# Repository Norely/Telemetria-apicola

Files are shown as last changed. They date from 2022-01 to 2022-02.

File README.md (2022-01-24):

# Telemetria-apicola
Screenshot from 2021-11-02 09-18-42

# Integrantes:
 - Juan Sebastian Martinez Valbuena
 - Elkin Alejandro Romero Hernandez
 - Gustavo Olarte Romero
 - Norely Jimenez Melenge

# ¿En que consiste el producto?
El producto consiste es un sistema de embebido que permite sensar la temperatura y mantenerla desde los 12°C hasta los 35°C,ya que en un apiario es importante que la temperatura no exceda los 38°C,para evitar que las abejas realizan trabajo extra,como salir a traer agua o realizar ventilación con sus alas. Además cuenta con un sistema de GPs que envía una notificación al celular,  en el cual es necesario para obtener la certificación que identifique su posición geográfica.

El módulo medirá temperatura, humedad y llenado de los tanques. Los actuadores constaría de un ventilador para refrigerar el ambiente y una resistencia en caso de requerir aumento de temperatura. Cuando los tanques estén llenos el módulo envía un mensaje de alerta a la interfaz que se haya elegido. También se puede incluir un módulo de alimentación artificial para que suministre agua azucarada en caso de ser necesario (se realizará 45 días antes de la floración y se suspende al inicio de la misma). 

# Componentes basicos
- ESP32 (Microcontrolador)
- Raspberry (Servidores)
- Sensor de humedad DHT11 (DIGITAL)  (12 - 35)°C
- Pantalla OLED
- Ventilador
- Microbomba
- Neo m7 (GPS)
- Regulador ASM1117 3.3V
- Driver L293D
- Convertidor MT3608
- BQ24070

# Requerimientos funcionales
* El apiario debe recopilar constantemente las variables de interés (temperatura y humedad)
* El sistema recolecta datos automáticamente para enviarlos a un servidor local.
* Mantener un ambiente controlado (parámetros ambientales)
* El sistema tendrá una Interfaz hombre máquina que permita la visualización de los parámetros medidos
* El apiario debe poseer módulos removibles para la obtención de miel.
* El sistema cuenta con monitoreo y control por parte del usuario en caso de falla de cualquier dispositivo electrónico.

# Requerimientos no funcionales
* El apiario debe funcionar todo el día.
* Debe garantizar la calidad apropiada de la miel
* El apiario debe usarse sólo por personal calificado.
* La interfaz hombre-máquina debe ser responsive.

# Hardware
***ESP 32***

Para pruebas del firmware y algunos componentes se hará uso de la siguiente tarjeta:
  
  
|Pin| Protocolo | Nombre |Dispositivo|
|-----|---|---|-----|
|33|I2C|SDA|Pantalla|
|36|I2C|SCL|Pantalla|
|34|UART|Rx|USB|
|35|UART|Tx|USB|
|23|UART|Rx|GPS|
|27|UART|Tx|GPS|
|24|GPIO| |Sensor T/H|
|26| | |Ventilador|
|29| | |Microbomba|
|13| | |Rele Bombilla|

Este tiene las siguientes caracteristicas:
- Procesador Tensilica Xtensa 32bits LX6 hasta 240MHz.
- Wi-Fi: 802.11b/g/n/e/i (802.11n @ 2.4 Ghz hasta 150 Mbit/s).
- Bluetooth: v4.2 BR/EDR y bluetooth  Low Energy (BLE).
- Rom:448 KiB.
- SRAM: 520 KiB.
- RTC slow SRAM: 8 KiB.
- RTC fast SRAM: 8 KiB.
- eFuse: 1 Kbit.
- Flash embebida: 0 MiB (ESP32-D0WDQ6, ESP32-D0WD, and ESP32-S0WD chips); 2 MiB (ESP32-D2WD chip); 4 MiB (ESP32-PICO-D4 SIP module).
- Periféricos compatibles: ADC, DAC, I2C, UART, Interfaz CAN 2.0, SPI, I2S, RMII y PWM entre otros.
- Seguridad tipo IEEE 802.11, WFA, WPA/WPA2 y WAPI.
- Encriptación de memoria Flash.
- Criptografía soportada por acelerador de hardware: AES, SHA-2, RSA, ECC, RNG.
- Voltaje de trabajo 3.3VDC.
- Energía y datos  via conector microUSB 5VDC.

En la tarjeta que estamos desarrollando se emplea el siguiente módulo (Esp 32-WROOM-32D): 
<p align="center">
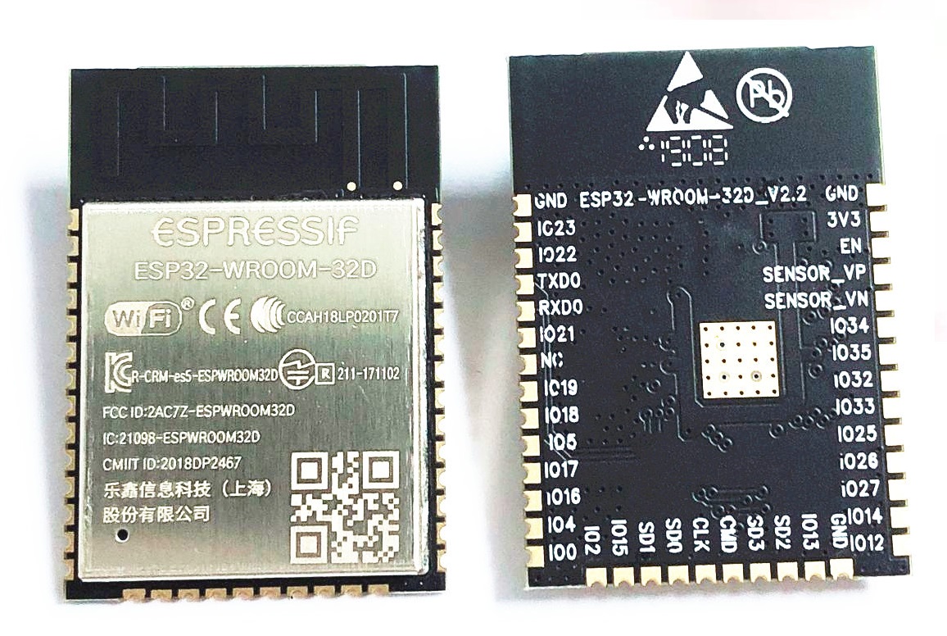
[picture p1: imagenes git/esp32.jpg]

</p>

Este se encuentra en SIGMA ELECTRONICA ([ESP 32](https://www.sigmaelectronica.net/producto/esp32-wroom-32d/)) y tambien su [Hoja de datos](https://github.com/Norely/Telemetria-apicola/blob/main/Hojas%20de%20datos/ESP32-WROOM-32D_pdf.pdf) de donde se puede obtener el esquematico de los perifericos para el módulo:

<p align="center">
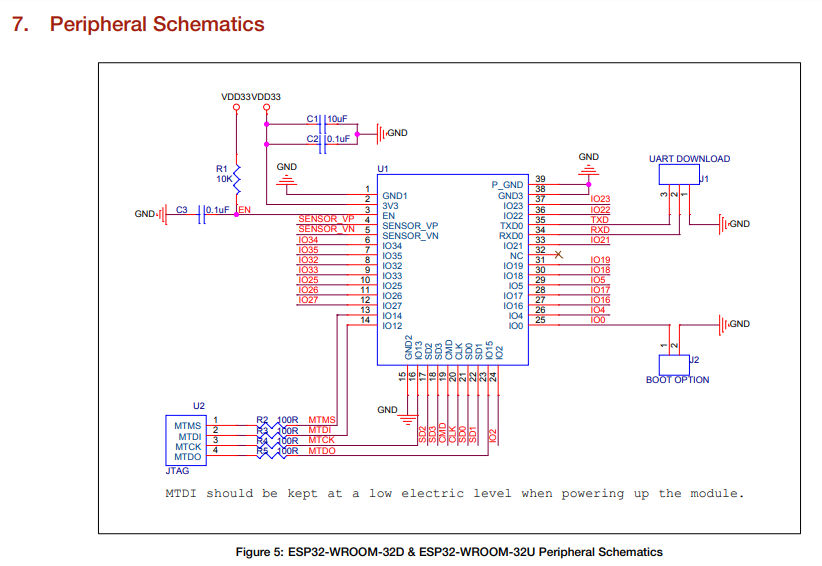
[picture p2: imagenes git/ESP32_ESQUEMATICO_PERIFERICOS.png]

</p>

***Raspberry PI4-4GB***

Esta tarjeta se considera para el montaje del servidor en donde se planea guardar la información obtenida del proyecto. 

<p align="center">
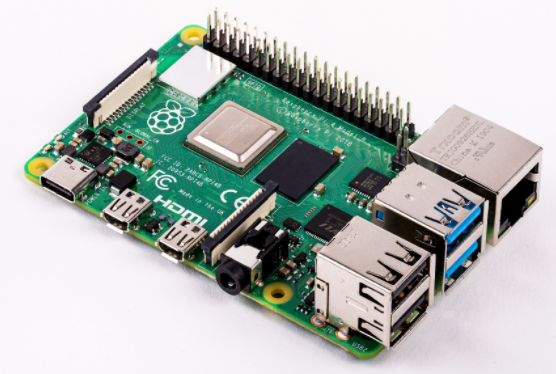
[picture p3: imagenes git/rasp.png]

</p>

Especificaciones:
- BCM2711 Broadcom, Quad Core Cortex-A72.
- 64-bit SoC @ 1,5 GHz.
- Memoria RAM: 4 GB.
- 2.4 GHz y 5.0 GHz IEEE 802.11b/g/n/ac inalámbrico LAN.
- Bluetooth 5.0 BLE.
- Gigabit Ethernet.
- 2 Puertos USB 2.0.
- 2 Puertos USB 3.0.
- Conector GPIO estándar de 40 pines (Totalmente compatible con las placas de desarrollo Raspberry PI anteriores).
- 2 puertos micro HDMI (compatible con hasta 4Kp60).
- Puerto de visualización MIPI DSI de 2 vías.
- Puerto de camara MIPI de 2 carriles.
- Puerto de vídeo compuesto y audio estéreo de 4 polos.
- H.265 (decodificador de 4Kp60).
- H.264 (decodificador 1080p60, 1080p30).
- OpenGL ES 3.0 gráficos.
- Ranura para tarjeta Micro SD para cargar el sistema operativo y el almacenamiento de datos.
- Alimentación de entrada por conector USB Tipo C: 5V – 3A.
- Alimentación de entrada por conector GPIO: 5V – 3A.
- Alimentación sobre Ethernet (PoE) habilitada (requiere un complemento adicional PoE por separado): 5V – 3A.

Este se encuentra en SIGMA ELECTRONICA ([RPI4-4GB](https://www.sigmaelectronica.net/producto/rpi4-4gb/)) y tambien su [Hoja de datos](https://github.com/Norely/Telemetria-apicola/blob/main/Hojas%20de%20datos/RASP.pdf)

***Sensor de humedad DHT11***

Este sensor permite obtener la lectura de temperatura y humedad, ademas su señal es digital por lo que facilita su comunicacion con la ESP 32.

<p align="center">
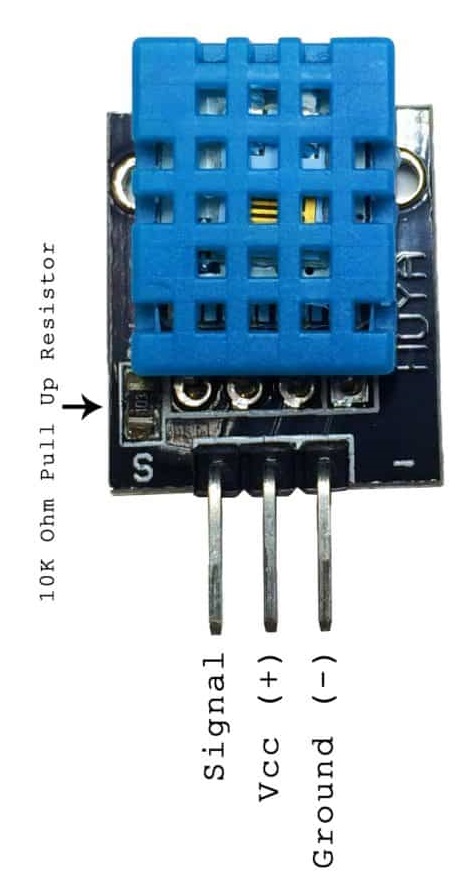
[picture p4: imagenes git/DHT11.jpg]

</p>

Especificaciones:
- humedad relativa 
-Resolución: 16 bit 
- Repetibilidad: ± 1% HR 
- Precisión: En 25 ℃ ± 5% de humedad relativa 
- Intercambiabilidad: totalmente intercambiables 
- Tiempo de respuesta: 1 / e (63%) de 25 ℃ 6s 1m / s 6s aire 
- Histéresis: <± 0,3% HR 
- Estabilidad a largo plazo: <± 0.5% RH / yr in temperatura 
- Resolución: 16 bit 
- Repetibilidad: ± 0,2 ℃ 
- Rango: A los 25 ℃ ± 2 ℃ 
- Tiempo de respuesta: 1 / e (63%) 10S 
- Características eléctricas 
- Fuente de alimentación: CC 3.5 ~ 5.5V 
- Corriente de alimentación: medida 0.3mA espera 60μ A 
- Periodo de muestreo: más de 2 segundos

Este se encuentra en SIGMA ELECTRONICA ([DHT11](https://www.sigmaelectronica.net/producto/dht11/)) y tambien su [Hoja de datos](https://github.com/Norely/Telemetria-apicola/blob/main/Hojas%20de%20datos/DHT11.pdf).

***Pantalla OLED***

Se elige una pantalla OLED como recomendación del docente porque es mas eficiente energeticamente y ademas a la cantidad de pixeles que manejan.

<p align="center">
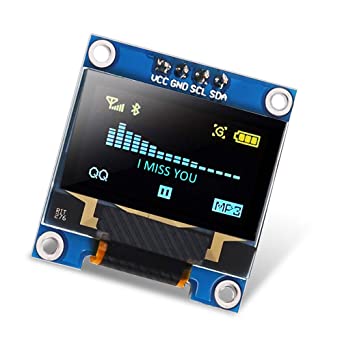
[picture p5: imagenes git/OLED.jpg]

</p>

Especificaciones:
- No necesita backlight.
- Color:Azul
- Resolución: 128x64.
- Voltaje: 3 a 5V.
- Temperatura de trabajo: -30ºC a 70ºC.
- Tamaño: 27 x 27 x 4.1 mm
- Interfaz: I2C IIC TWI
- Driver: SSD1306
- Consumo: 0.08W

Este se encuentra en Dualtronica ([Pantalla OLED](https://dualtronica.com/pantallas/396-pantalla-oled-096-azul-comunicacion-i2c.html)). La [Hoja de datos](https://github.com/Norely/Telemetria-apicola/blob/main/Hojas%20de%20datos/SSD1306.pdf) corresponde al driver SSD1306 .

***Ventilador***

El medio de refrigeracion que se empleará será un ventilador PI.

<p align="center">
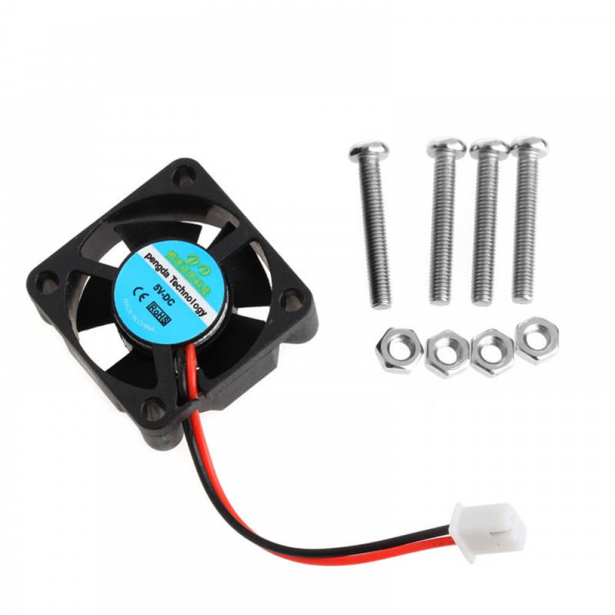
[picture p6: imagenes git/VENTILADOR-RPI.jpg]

</p>

Especificaciones: 
- Voltaje de funcionamiento: 5 V.
- Corriente nominal: 0.2 A.
- Dimensiones: 30 mm x 30 mm x 10 mm.

Este se encuentra en SIGMA ELECTRONICA ([Ventilador RPI](https://www.sigmaelectronica.net/producto/ventilador-pi/)) y su [Hoja de datos](https://github.com/Norely/Telemetria-apicola/blob/main/Hojas%20de%20datos/VENTILADOR.pdf).

***Microbomba***

Para surtir alimentación artificial al apiario, se emplea el uso de esta microbomba. Se eligío por encima de la valvula solenoide porque esta requiere un caudal minimo ademas de su relativo costo elevado. 

<p align="center">
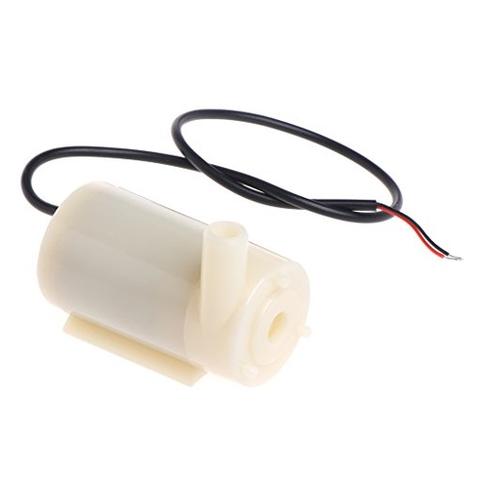
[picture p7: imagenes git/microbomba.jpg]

</p>

Especificaciones:
- Voltaje de Alimentación: 2.5-6VDC.
- Elevación máxima: 40-110cm.
- Caudal: 80-100L/H.
- Diámetro exterior de la salida de agua: 7.5 mm.
- Diámetro interior de salida de agua: 4.7 mm.
- Diámetro : Aprox. 24 mm.
- Longitud: Aprox. 45 mm.
- Altura: aprox. 33 mm.
- Material: Plástico.
- Vida útil de trabajo continuo de 500 horas.

Este se encuentra en SIGMA ELECTRONICA ([Microbomba](https://www.sigmaelectronica.net/producto/sig0833/)).

***Neo M6***

Se emplea el módulo NEO-6M para emplearlo a parte de la tarjeta a desarrollar dadas las condiciones que requiere un modulo gps en la misma tarjeta como estar lejos de ciertos componentes como capacitores, ademas de la antena de la esp 32 con la que podria haber interferencia.

<p align="center">
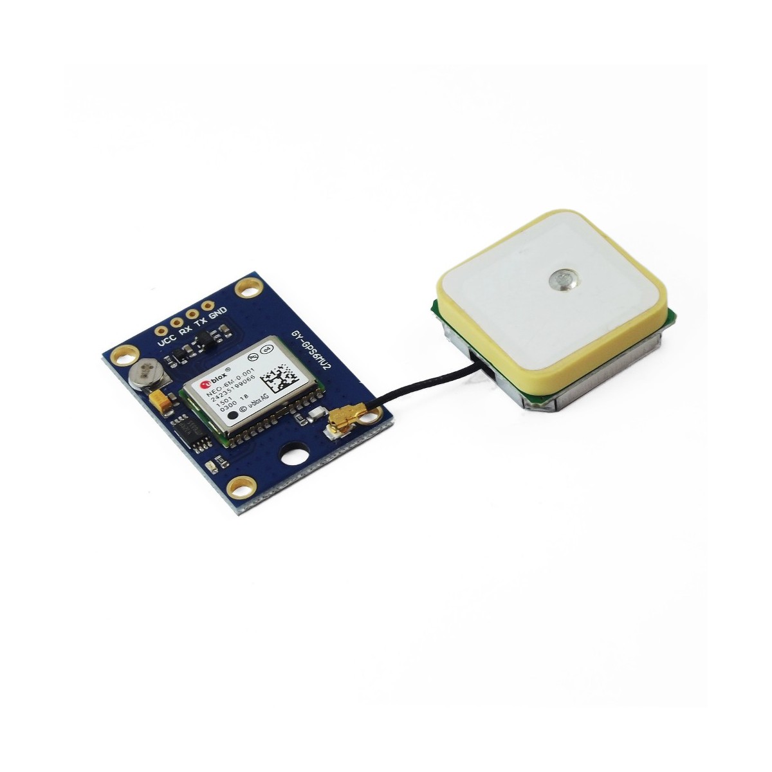
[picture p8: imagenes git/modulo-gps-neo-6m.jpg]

</p>

Especificaciones:
- Ultra sensibilidad: -165dBm
- 22 tracking/66 acquisition-channel receiver
- Coporta estándares WAAS/EGNOS/MSAS/GAGAN
- Frecuencia de actualización 5Hz velocidad de desplazamiento máxima: 500m/seg
- Protocolo NMEA  (a 9600bps)
- 01 puerto serial
- Antena incorporada de 18.2 x 18.2 x 4.0 mm
- Rango de temperatura: -40 to 85 C
- Cumple estándar RoHS
- Tamano reducido 30mm x20mm x 11.4mm

Este se encuentra en Dualtronica ([GPS NEO-6M](https://dualtronica.com/modulos/86-modulo-gps-neo-6m.html)) y su [Hoja de datos](https://github.com/Norely/Telemetria-apicola/blob/main/Hojas%20de%20datos/GY-NEO-6M-V2-pdf.pdf).

# Software
  

Para esta parte se realiza la [instalación](https://docs.micropython.org/en/latest/esp32/tutorial/intro.html#esp32-intro) para el ESP-32, del firmware mycropython. 
  
Este compilador permite realizar algunas acciones como la manipulación de los pines del microcontrolador, Interactuar con los protocolos de comunicacion (I2C, SPI, PWM, etc), Manejo de tiempos entre muchas otras.

## Ejemplos:

#### Pins
~~~
from machine import Pin

p0 = Pin(0, Pin.OUT)    # create output pin on GPIO0
p0.on()                 # set pin to "on" (high) level
p0.off()                # set pin to "off" (low) level
p0.value(1)             # set pin to on/high

p2 = Pin(2, Pin.IN)     # create input pin on GPIO2
print(p2.value())       # get value, 0 or 1

p4 = Pin(4, Pin.IN, Pin.PULL_UP) # enable internal pull-up resistor
p5 = Pin(5, Pin.OUT, value=1) # set pin high on creation
~~~

#### Protocolo
~~~
from machine import Pin, SoftI2C

i2c = SoftI2C(scl=Pin(5), sda=Pin(4), freq=100000)

i2c.scan()              # scan for devices

i2c.readfrom(0x3a, 4)   # read 4 bytes from device with address 0x3a
i2c.writeto(0x3a, '12') # write '12' to device with address 0x3a

buf = bytearray(10)     # create a buffer with 10 bytes
i2c.writeto(0x3a, buf)  # write the given buffer to the peripheral
~~~

#### Tiempo
~~~
import time

time.sleep(1)           # sleep for 1 second
time.sleep_ms(500)      # sleep for 500 milliseconds
time.sleep_us(10)       # sleep for 10 microseconds
start = time.ticks_ms() # get millisecond counter
delta = time.ticks_diff(time.ticks_ms(), start) # compute time difference
~~~

# Modelo 3D Diseño PCB

<p align="center">
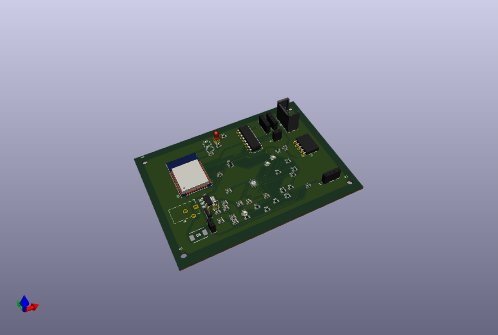
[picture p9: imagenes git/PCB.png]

</p>

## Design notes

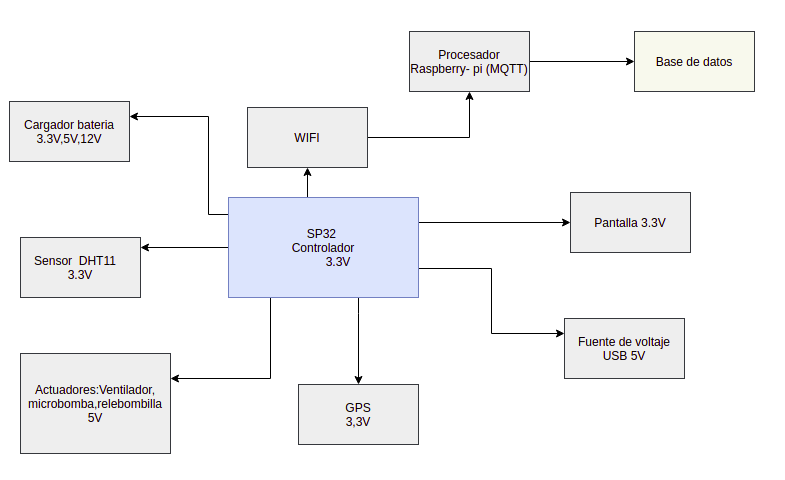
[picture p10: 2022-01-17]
DiagramaBloques.png

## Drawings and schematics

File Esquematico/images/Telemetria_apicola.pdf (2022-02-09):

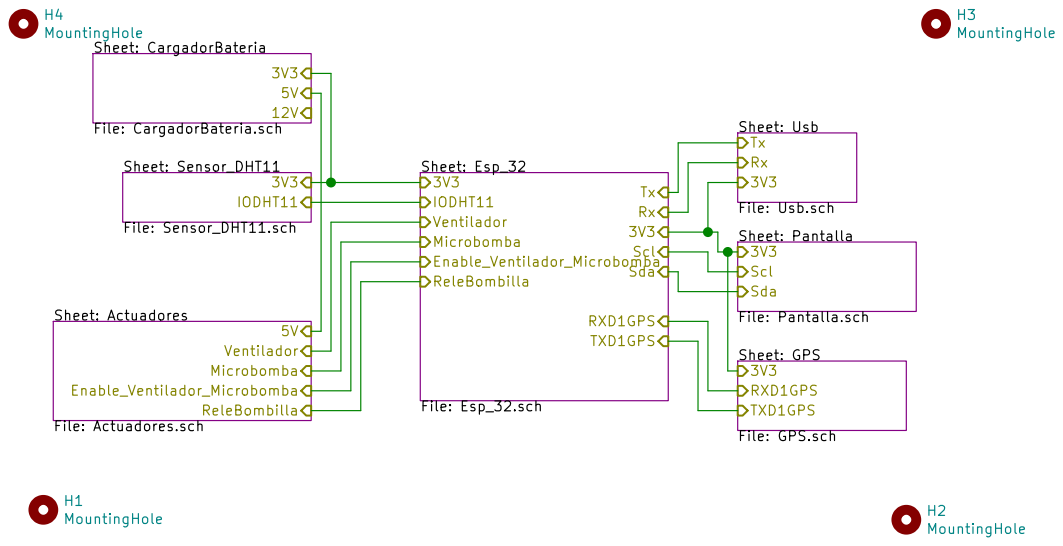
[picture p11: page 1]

TXD1GPS ReleBombilla Sheet: Sensor_DHT11 File: Sensor_DHT11.sch

Sheet: Pantalla File: Pantalla.sch

3V3 Sheet: Actuadores File: Actuadores.sch

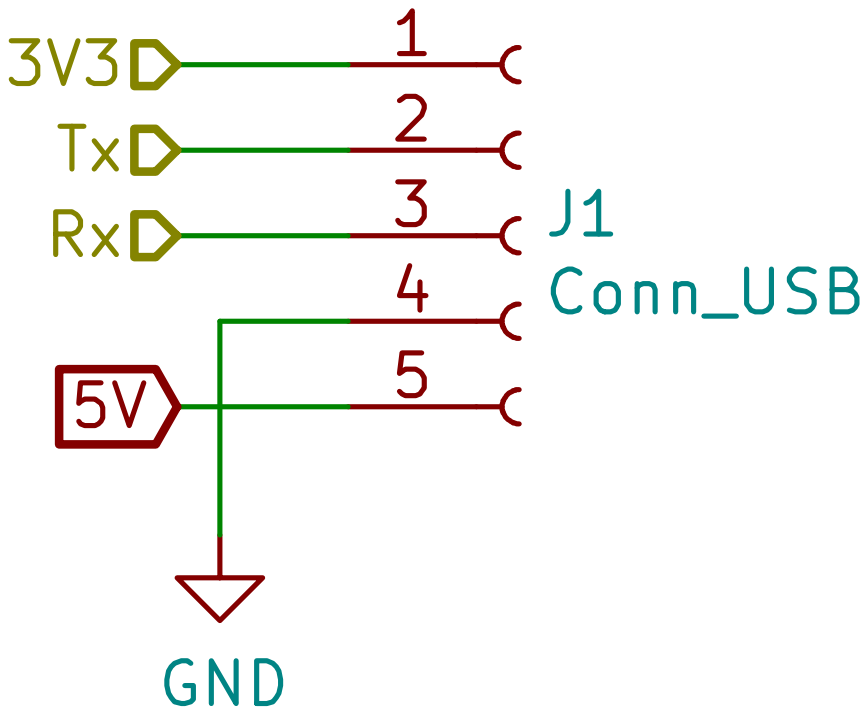
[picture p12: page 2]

Id: 2/8 Title: File: Usb.sch Sheet: /Usb/ GND

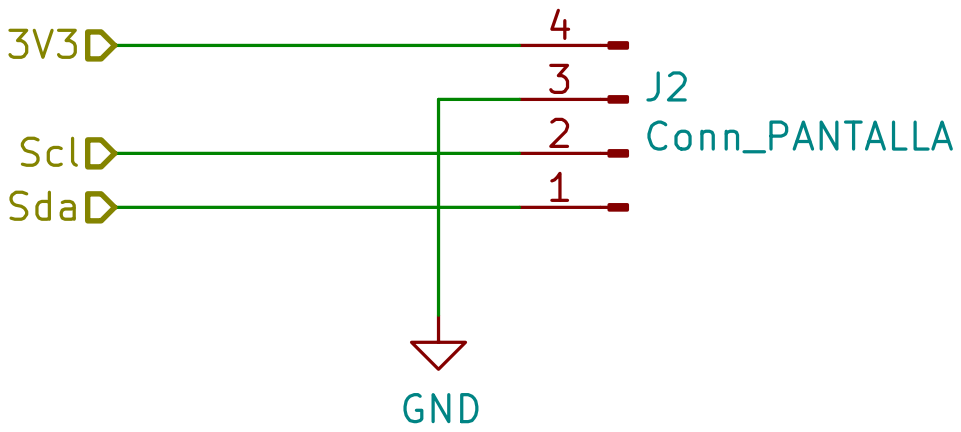
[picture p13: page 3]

Id: 3/8 Title: File: Pantalla.sch Sheet: /Pantalla/

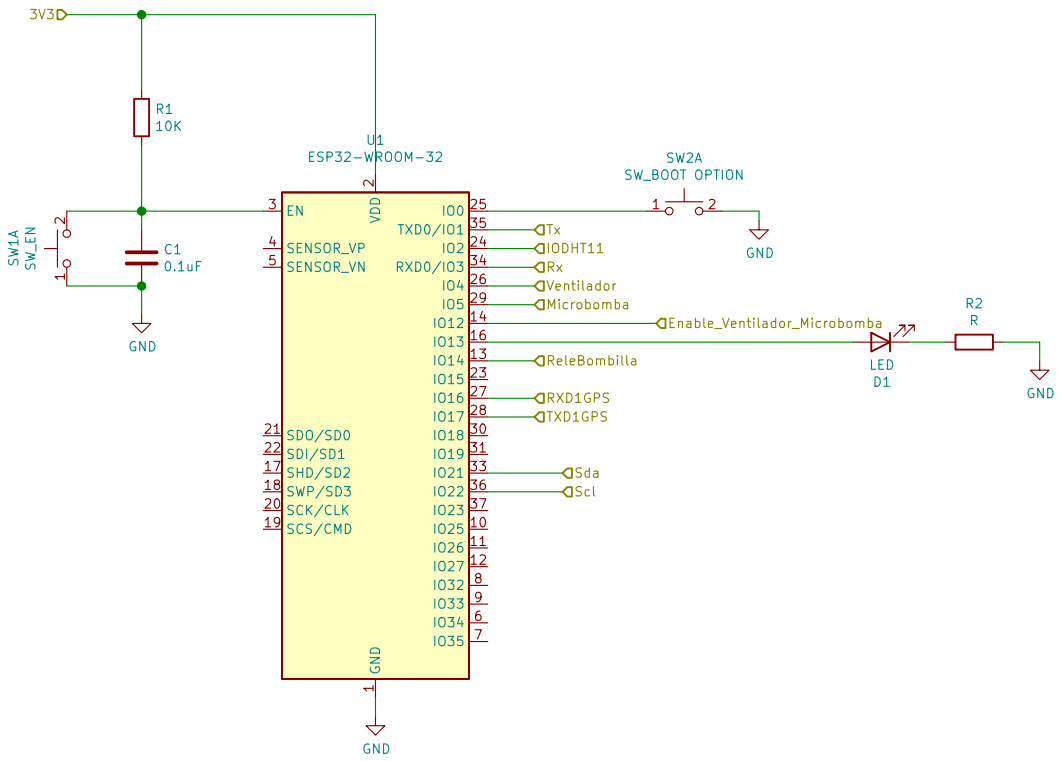
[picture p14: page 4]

2 SCK/CLK 20 SDO/SD0 21 SDI/SD1 22

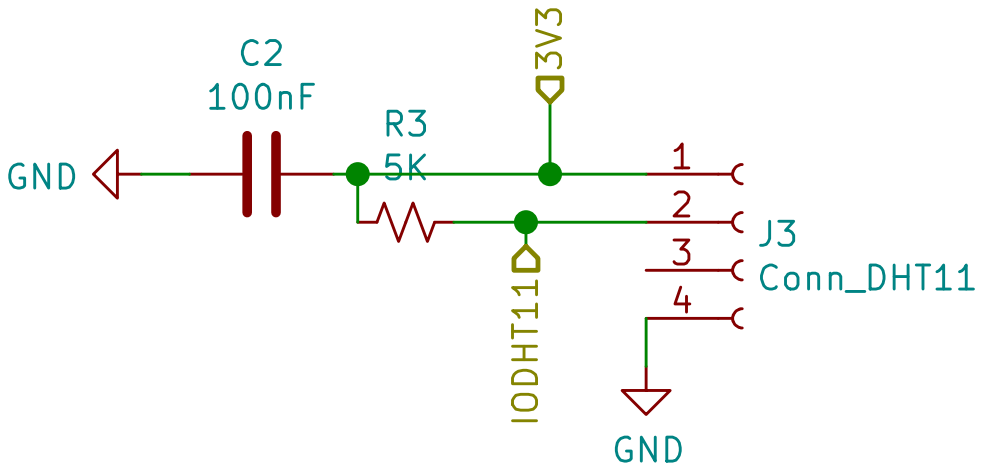
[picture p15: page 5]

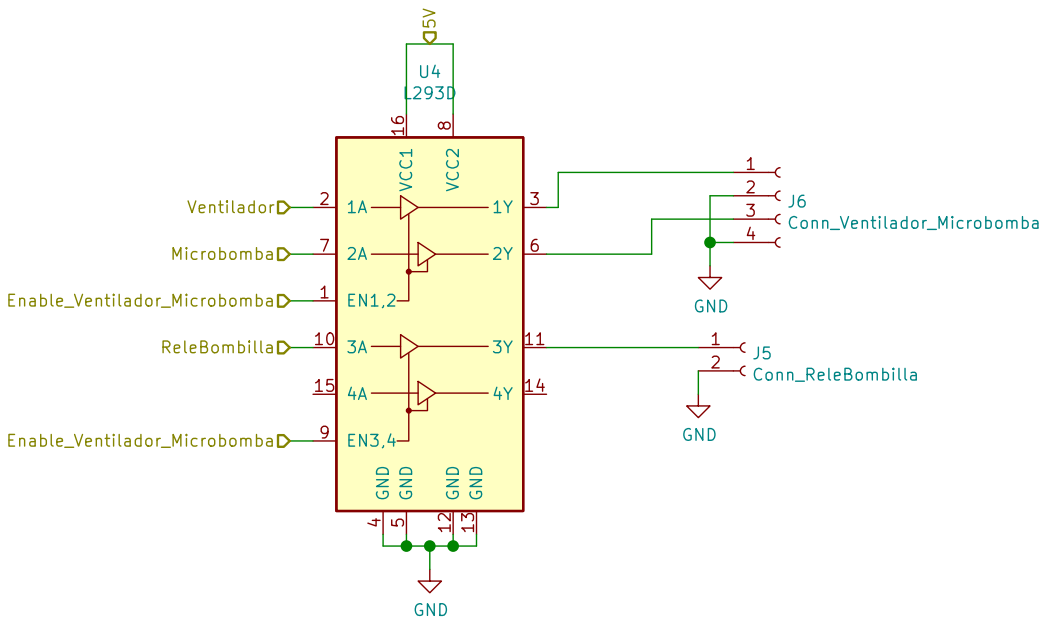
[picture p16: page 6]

Id: 6/8 Title: File: Actuadores.sch Sheet: /Actuadores/

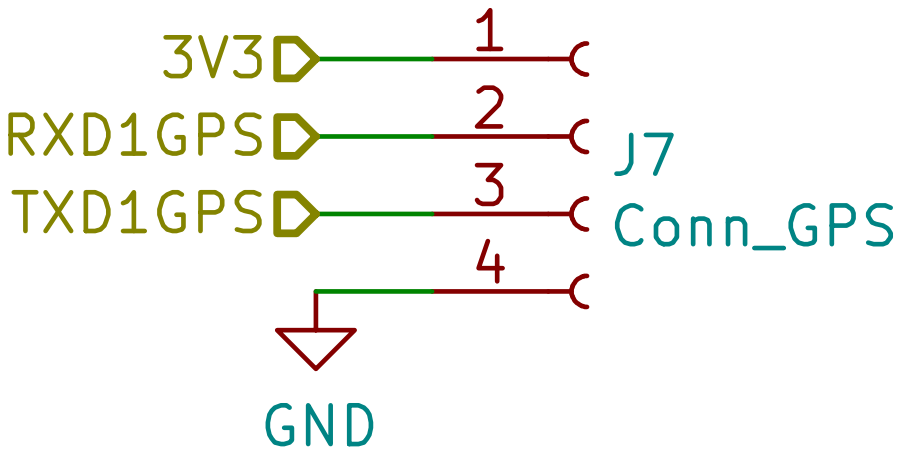
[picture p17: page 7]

Id: 7/8 Title: File: GPS.sch Sheet: /GPS/

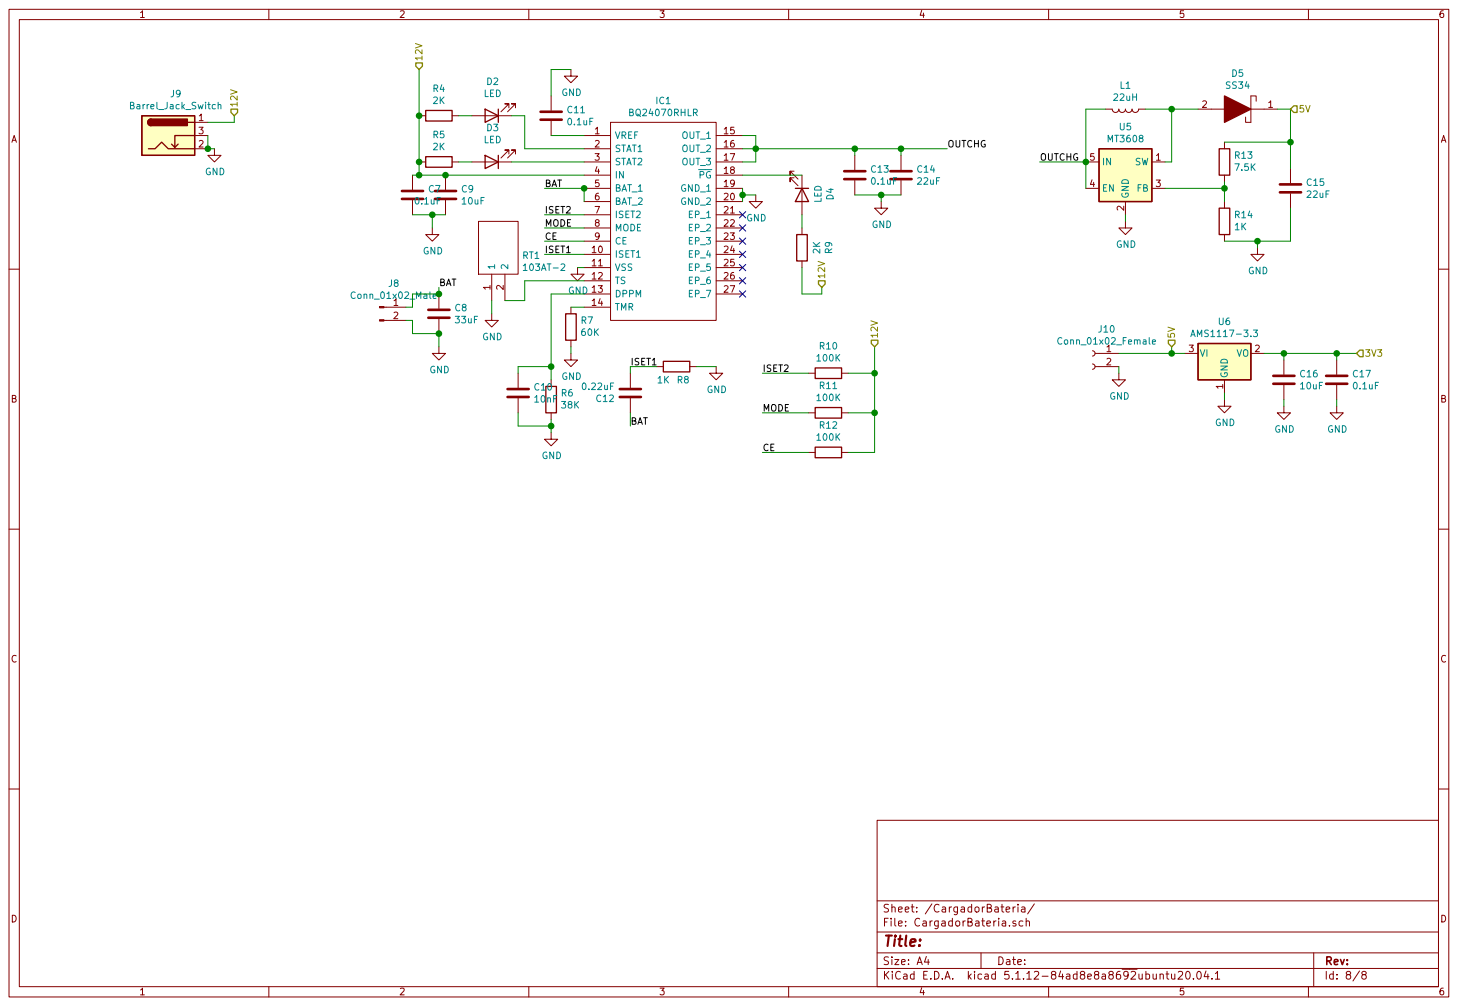
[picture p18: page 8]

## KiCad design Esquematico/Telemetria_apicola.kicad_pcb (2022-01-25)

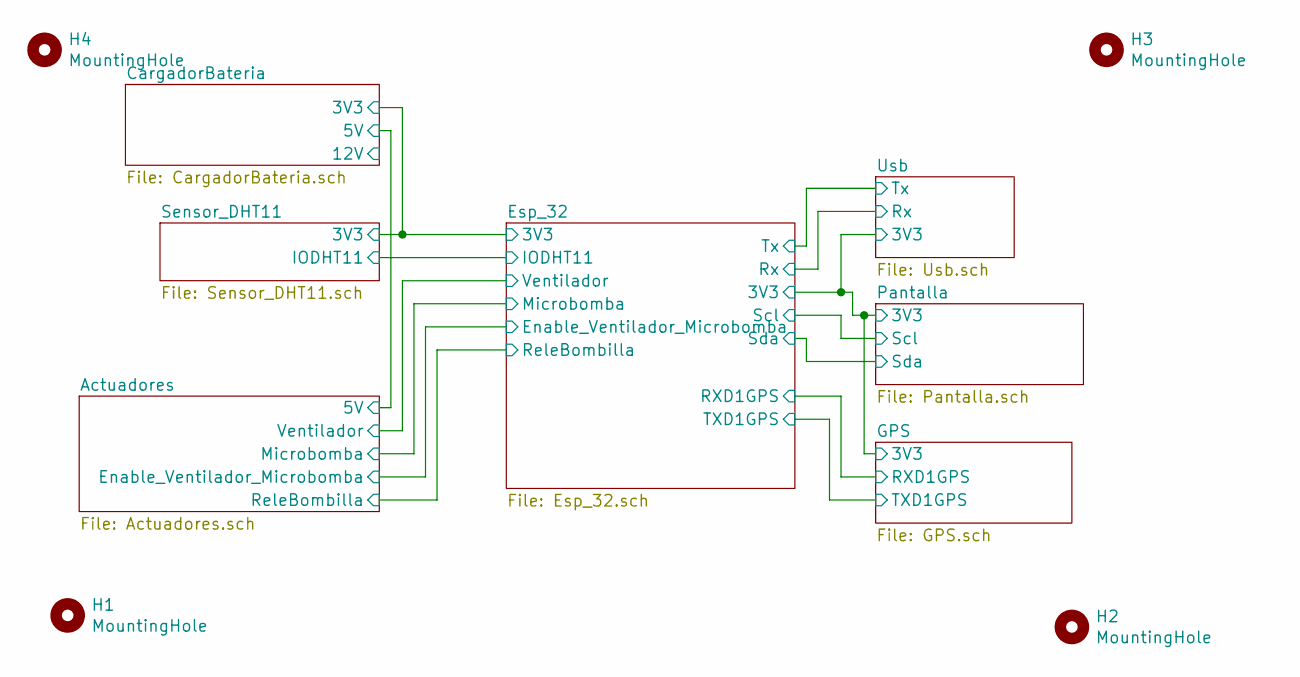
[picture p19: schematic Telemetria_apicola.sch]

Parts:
H1, H2, H3, H4: MountingHole; MountingHole_3.2mm_M3_ISO7380

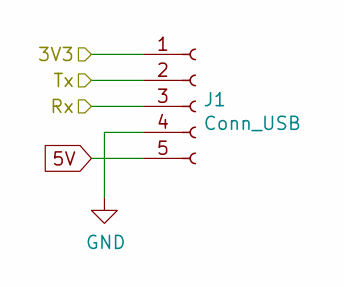
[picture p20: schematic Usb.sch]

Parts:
J1: Conn_USB; PinSocket_1x05_P2.54mm_Horizontal

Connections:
5V: J1.5
/CargadorBateria/3V3: J1.1; also elsewhere on the board
/Esp_32/Rx: J1.3; also elsewhere on the board
/Esp_32/Tx: J1.2; also elsewhere on the board
GND: J1.4; also elsewhere on the board

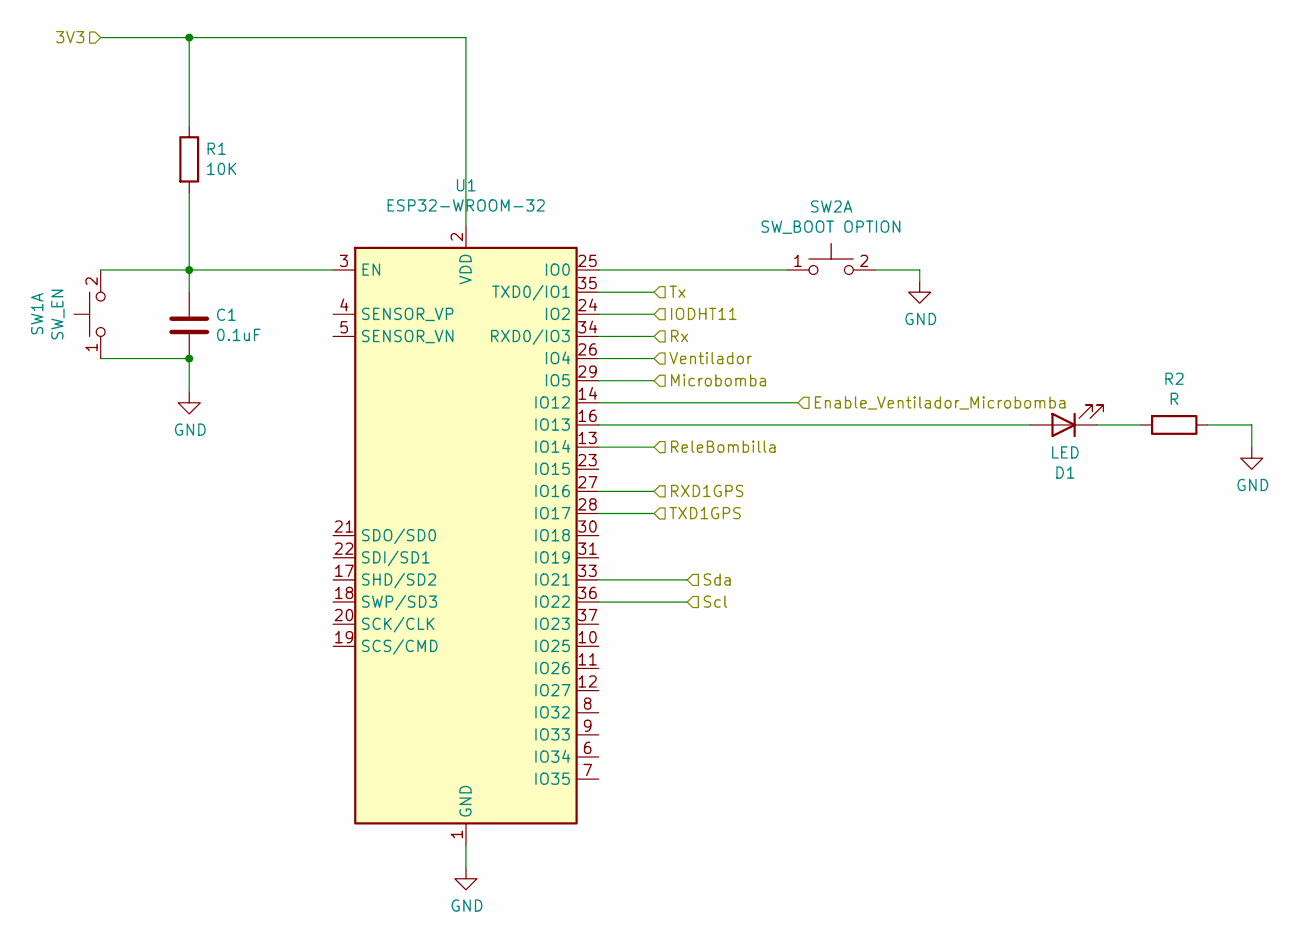
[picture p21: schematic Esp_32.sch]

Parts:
C1: 0.1uF; C_0805_2012Metric_Pad1.18x1.45mm_HandSolder
D1: LED; LED_D3.0mm
R1: 10K; R_0805_2012Metric_Pad1.20x1.40mm_HandSolder
R2: R; R_0805_2012Metric_Pad1.20x1.40mm_HandSolder
SW1: SW_EN; SW_Push_1P1T_NO_CK_KMR2
SW2: SW_BOOT OPTION; SW_Push_1P1T_NO_CK_KMR2
U1: ESP32-WROOM-32

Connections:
/Actuadores/Enable_Ventilador_Microbomba: U1.14 (IO12); also elsewhere on the board
/Actuadores/Microbomba: U1.29 (IO5); also elsewhere on the board
/Actuadores/ReleBombilla: U1.13 (IO14); also elsewhere on the board
/Actuadores/Ventilador: U1.26 (IO4); also elsewhere on the board
/CargadorBateria/3V3: R1.1, U1.2 (VDD); also elsewhere on the board
/Esp_32/IODHT11: U1.24 (IO2); also elsewhere on the board
/Esp_32/RXD1GPS: U1.27 (IO16); also elsewhere on the board
/Esp_32/Rx: U1.34 (RXD0/IO3); also elsewhere on the board
/Esp_32/Scl: U1.36 (IO22); also elsewhere on the board
/Esp_32/Sda: U1.33 (IO21); also elsewhere on the board
/Esp_32/TXD1GPS: U1.28 (IO17); also elsewhere on the board
/Esp_32/Tx: U1.35 (TXD0/IO1); also elsewhere on the board
GND: C1.2, R2.1, SW1.1 (C), SW2.2 (D), U1.1 (GND), U1.15 (GND), U1.38 (GND), U1.39 (GND); also elsewhere on the board
unnamed: C1.1, R1.2, SW1.2 (D), U1.3 (EN)
unnamed: D1.1 (K), R2.2
unnamed: D1.2 (A), U1.16 (IO13)
unnamed: SW2.1 (C), U1.25 (IO0)

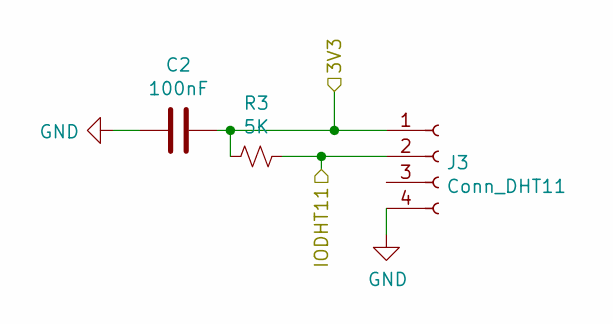
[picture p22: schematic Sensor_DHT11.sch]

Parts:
C2: 100nF; C_0805_2012Metric_Pad1.18x1.45mm_HandSolder
J3: Conn_DHT11; PinSocket_1x04_P2.54mm_Vertical
R3: 5K; R_0805_2012Metric_Pad1.20x1.40mm_HandSolder

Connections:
/CargadorBateria/3V3: C2.1, J3.1, R3.2; also elsewhere on the board
/Esp_32/IODHT11: J3.2, R3.1; also elsewhere on the board
GND: C2.2, J3.4; also elsewhere on the board

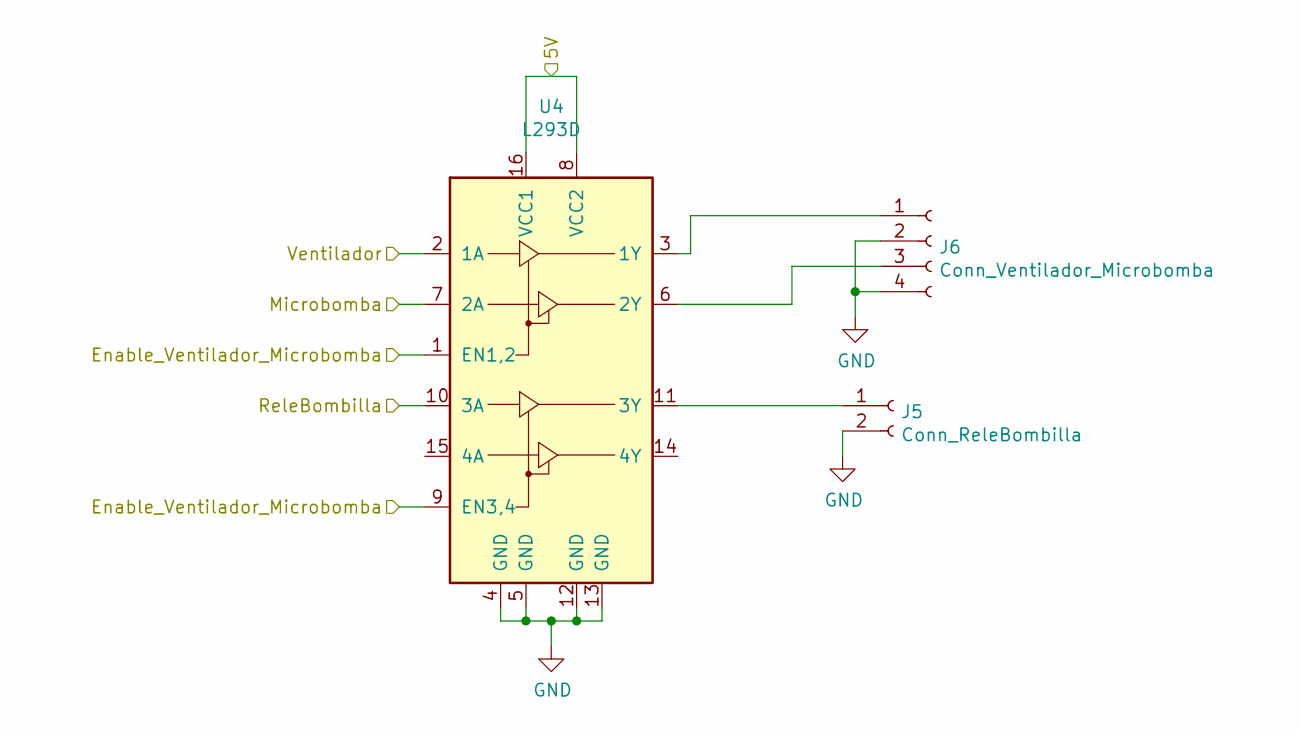
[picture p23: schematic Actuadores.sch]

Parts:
J5: Conn_ReleBombilla; PinSocket_1x02_P2.54mm_Vertical
J6: Conn_Ventilador_Microbomba; PinSocket_1x04_P2.54mm_Vertical
U4: L293D; DIP-16_W7.62mm

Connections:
/Actuadores/5V: U4.8 (VCC2), U4.16 (VCC1); also elsewhere on the board
/Actuadores/Enable_Ventilador_Microbomba: U4.1 (EN1,2), U4.9 (EN3,4); also elsewhere on the board
/Actuadores/Microbomba: U4.7 (2A); also elsewhere on the board
/Actuadores/ReleBombilla: U4.10 (3A); also elsewhere on the board
/Actuadores/Ventilador: U4.2 (1A); also elsewhere on the board
GND: J5.2, J6.2, J6.4, U4.4 (GND), U4.5 (GND), U4.12 (GND), U4.13 (GND); also elsewhere on the board
unnamed: J5.1, U4.11 (3Y)
unnamed: J6.1, U4.3 (1Y)
unnamed: J6.3, U4.6 (2Y)

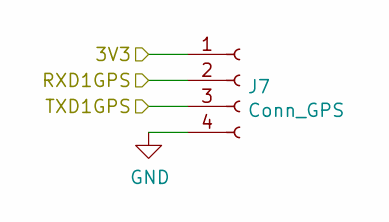
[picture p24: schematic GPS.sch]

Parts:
J7: Conn_GPS; PinSocket_1x04_P2.54mm_Vertical

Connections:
/CargadorBateria/3V3: J7.1; also elsewhere on the board
/Esp_32/RXD1GPS: J7.2; also elsewhere on the board
/Esp_32/TXD1GPS: J7.3; also elsewhere on the board
GND: J7.4; also elsewhere on the board

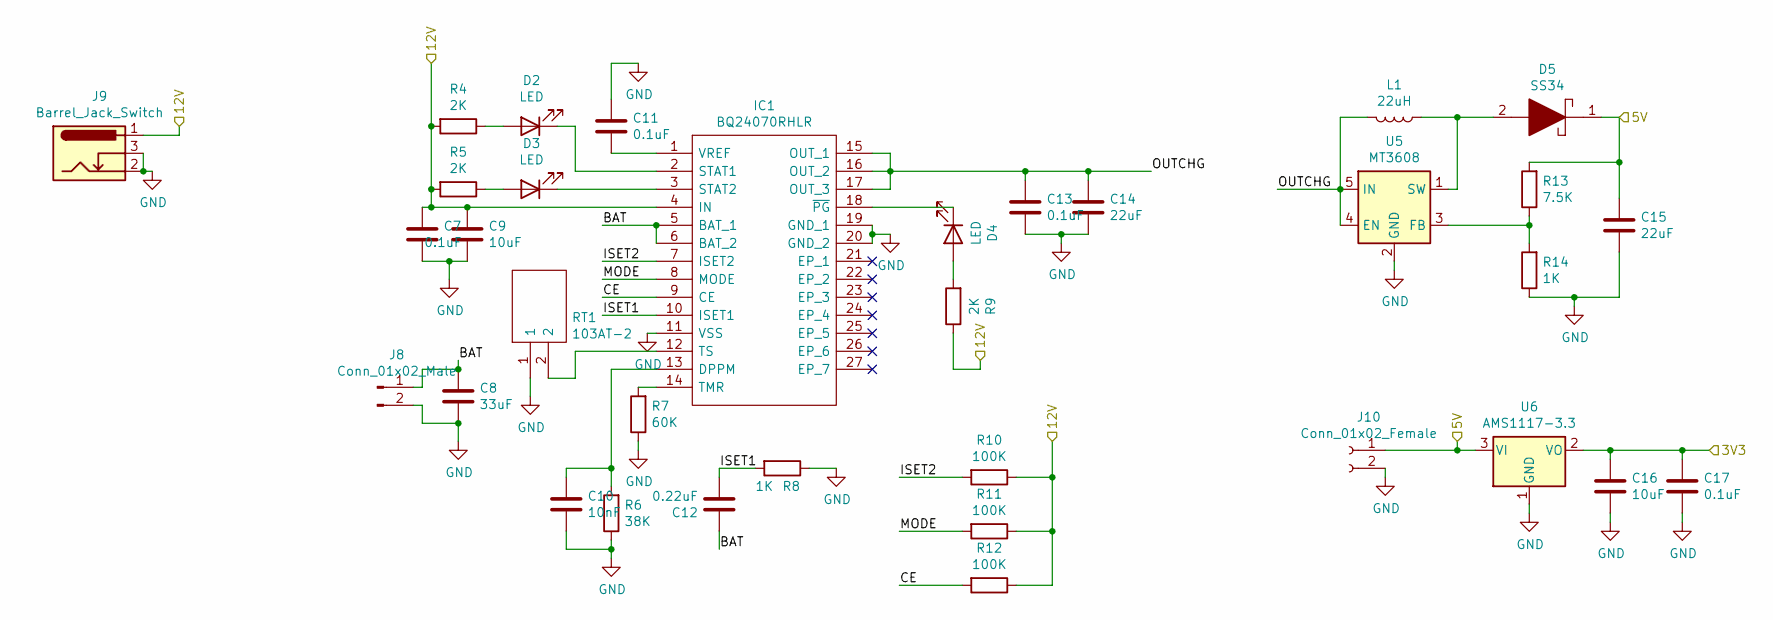
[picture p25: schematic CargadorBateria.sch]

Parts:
C7, C11, C13, C17: 0.1uF; C_0805_2012Metric_Pad1.18x1.45mm_HandSolder
C8: 33uF; C_0805_2012Metric_Pad1.18x1.45mm_HandSolder
C9, C16: 10uF; C_0805_2012Metric_Pad1.18x1.45mm_HandSolder
C10: 10nF; C_0805_2012Metric_Pad1.18x1.45mm_HandSolder
C12: 0.22uF; C_0805_2012Metric_Pad1.18x1.45mm_HandSolder
C14, C15: 22uF; C_0805_2012Metric_Pad1.18x1.45mm_HandSolder
D2, D3, D4: LED; LED_0805_2012Metric_Pad1.15x1.40mm_HandSolder
D5: SS34; DIONM7959X262N; Manufacturer_Part_Number SS34
IC1: BQ24070RHLR; BQ24032ARHLR; Manufacturer_Part_Number BQ24070RHLR; Mouser Part Number 595-BQ24070RHLR
J8: Conn_01x02_Male; PinHeader_1x02_P2.54mm_Vertical
J9: Barrel_Jack_Switch; BarrelJack_CUI_PJ-102AH_Horizontal
J10: Conn_01x02_Female; PinSocket_1x02_P2.54mm_Vertical
L1: 22uH; L_0805_2012Metric
R4, R5, R9: 2K; R_0805_2012Metric_Pad1.20x1.40mm_HandSolder
R6: 38K; R_0805_2012Metric_Pad1.20x1.40mm_HandSolder
R7: 60K; R_0805_2012Metric_Pad1.20x1.40mm_HandSolder
R8, R14: 1K; R_0805_2012Metric_Pad1.20x1.40mm_HandSolder
R10, R11, R12: 100K; R_0805_2012Metric_Pad1.20x1.40mm_HandSolder
R13: 7.5K; R_0805_2012Metric_Pad1.20x1.40mm_HandSolder
RT1: 103AT-2; R_Axial_DIN0204_L3.6mm_D1.6mm_P2.54mm_Vertical; Manufacturer_Part_Number 103AT-2; Mouser Part Number 954-103AT-2
U5: MT3608; SOT-23-6
U6: AMS1117-3.3; SOT-223-3_TabPin2

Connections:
/Actuadores/5V: C15.1, D5.1, J10.1, R13.2, U6.3 (VI); also elsewhere on the board
/CargadorBateria/3V3: C16.1, C17.1, U6.2 (VO); also elsewhere on the board
/CargadorBateria/12V: C7.1, C9.1, IC1.4 (IN), J9.1, R4.2, R5.2, R9.1, R10.1, R11.1, R12.1
/CargadorBateria/BAT: C8.1, C12.1, IC1.5 (BAT_1), IC1.6 (BAT_2), J8.1
/CargadorBateria/CE: IC1.9 (CE), R12.2
/CargadorBateria/ISET1: C12.2, IC1.10 (ISET1), R8.2
/CargadorBateria/ISET2: IC1.7 (ISET2), R10.2
/CargadorBateria/MODE: IC1.8 (MODE), R11.2
/CargadorBateria/OUTCHG: C13.1, C14.1, IC1.15 (OUT_1), IC1.16 (OUT_2), IC1.17 (OUT_3), L1.2, U5.4 (EN), U5.5 (IN)
GND: C7.2, C8.2, C9.2, C10.2, C11.1, C13.2, C14.2, C15.2, C16.2, C17.2, IC1.11 (VSS), IC1.19 (GND_1), IC1.20 (GND_2), J8.2, J9.2, J9.3, J10.2, R6.1, R7.1, R8.1, R14.1, RT1.1, U5.2 (GND), U6.1 (GND); also elsewhere on the board
unnamed: C10.1, IC1.13 (DPPM), R6.2
unnamed: C11.2, IC1.1 (VREF)
unnamed: D2.1 (K), IC1.2 (STAT1)
unnamed: D2.2 (A), R4.1
unnamed: D3.1 (K), IC1.3 (STAT2)
unnamed: D3.2 (A), R5.1
unnamed: D4.1 (K), IC1.18 (~PG)
unnamed: D4.2 (A), R9.2
unnamed: D5.2, L1.1, U5.1 (SW)
unnamed: IC1.12 (TS), RT1.2
unnamed: IC1.14 (TMR), R7.2
unnamed: R13.1, R14.2, U5.3 (FB)

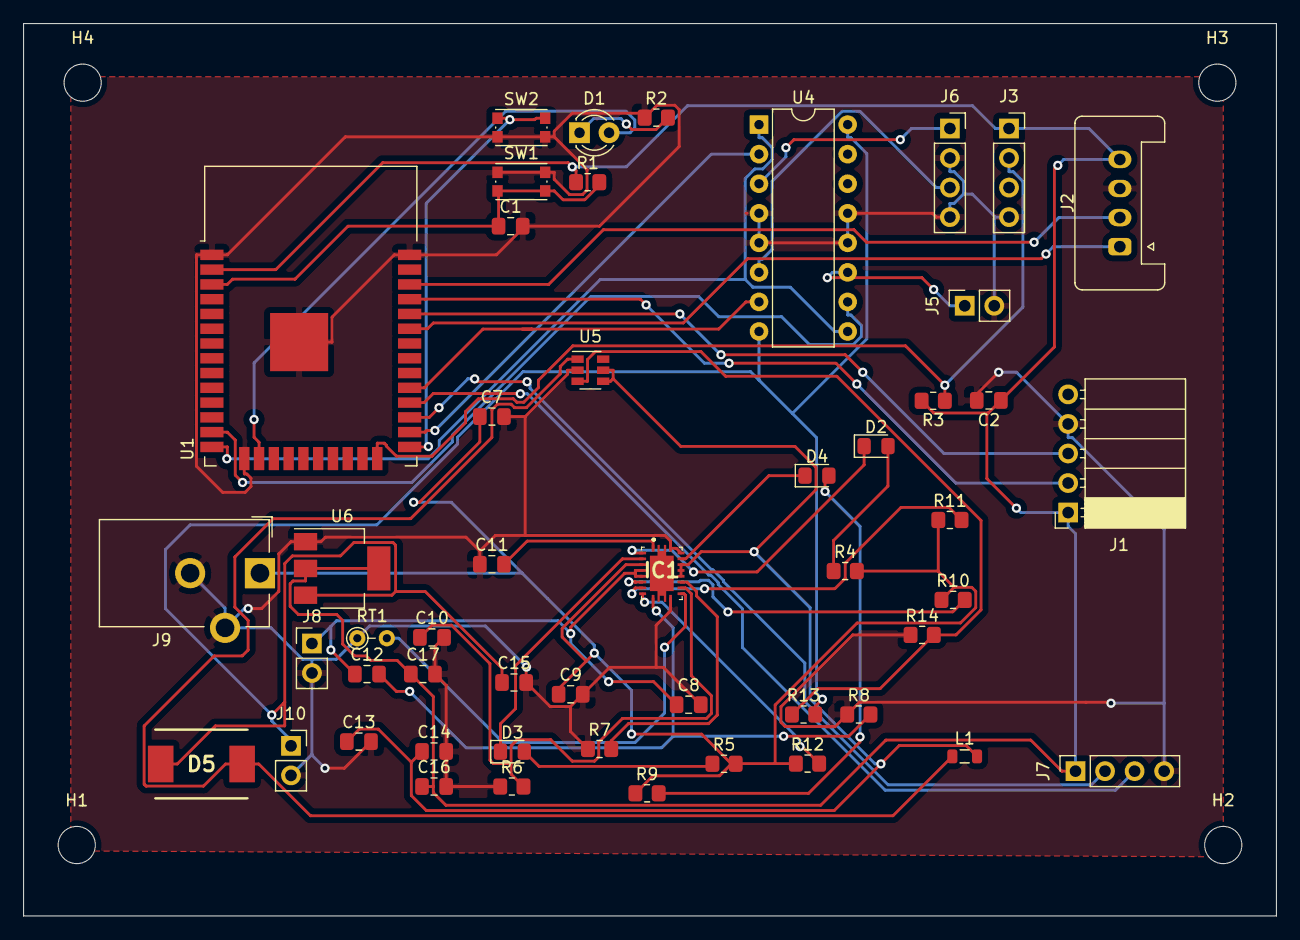
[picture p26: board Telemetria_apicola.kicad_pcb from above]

Board: 2 copper layers, 107.7 x 76.7 mm, 54 parts (0 on the bottom side), 40 nets.

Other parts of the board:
J2: Conn_PANTALLA; Stocko_MKS_1654-6-0-404_1x4_P2.50mm_Vertical

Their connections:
/CargadorBateria/3V3: J2.4; also elsewhere on the board
/Esp_32/Scl: J2.2; also elsewhere on the board
/Esp_32/Sda: J2.1; also elsewhere on the board
GND: J2.3; also elsewhere on the board

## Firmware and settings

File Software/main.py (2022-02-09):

from machine import UART, I2C
import machine
import dht
import  network

#DHT variables
dht_pin = 24
#UART variables
baudrate=9600
u2tx = 16
u2rx = 15 

d = dht.DHT11(machine.Pin(dht_pin))

uart = UART(1, baudrate=9600, tx=u2tx, rx=u2rx)  # init with given baudrate
uart.init(9600, bits=8, parity=None, stop=1) # init with given parameters

ssid = ''
passwd = ''

def do_connect():
    wlan = network.WLAN(network.STA_IF)
    wlan.active(True)
    if not wlan.isconnected():
        print('connecting to network...')
        wlan.connect(ssid, passwd)
        while not wlan.isconnected():
            pass
    print('network config:', wlan.ifconfig())
    
def gps_pos():
    b_data = uart.read()        # read 28all available characters
    s_data = b_data.decode('utf-8')

    l_data = s_data.split('\n')

    gpl = '$GPGLL'

    while True:
        for line in l_data:
            word = line.split(',')
            if word[0] == gpl:
                lat = (word[1], word[2])
                lon = (word[3], word[4])
                break
                
        
    print(f'Posición: {lat[0]} {lat[1]}, {lon[0]} {lon[1]}')
    
d.measure()
temp = d.temperature() # eg. 23 (°C)
hum = d.humidity()    # eg. 41 (% RH)

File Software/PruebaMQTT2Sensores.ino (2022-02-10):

#include <Wire.h>
#include <BH1750.h>
#include <WiFi.h>
#include <PubSubClient.h>

const char* ssid= "FAMILIA MARTINEZ ";
const char* password= "22528561mvl";
const char* mqtt_server = "192.168.1.72";

#define mqtt_port 1883
//#define MQTT_USER "usuario1"
//#define MQTT_PASSWORD "contrasena1"
#define MQTT_SERIAL_PUBLISH_CH_1 "oficina/ESP32/luz1"
#define MQTT_SERIAL_RECEIVER_CH_1 "oficina/ESP32/luz1"
#define MQTT_SERIAL_PUBLISH_CH_2 "oficina/ESP32/luz2"
#define MQTT_SERIAL_RECEIVER_CH_2 "oficina/ESP32/luz2"
double lux1 =0;
double lux2 =0;

//BH1750 lightMeter(0x5C);
BH1750 bh1750_a;
BH1750 bh1750_b;

/* Conexión Wifi y MQTT */ 
WiFiClient wifiClient;
PubSubClient client(wifiClient); // WiFiClient espClient; PubSubClient client(espClient);

// conexión a WiFi
void setup_wifi() {
    delay(10);
    // We start by connecting to a WiFi network
    Serial.println();
    Serial.print("Connecting to ");
    Serial.println(ssid);
    WiFi.begin(ssid, password);
    while (WiFi.status() != WL_CONNECTED) {
      delay(500);
      Serial.print(".");
    }
    randomSeed(micros());
    Serial.println("");
    Serial.println("WiFi connected");
    Serial.println("IP address: ");
    Serial.println(WiFi.localIP());
}
// conexion a MQTT
void reconnect() {
  // Loop until we're reconnected
  while (!client.connected()) {
    Serial.print("Attempting MQTT connection...");
    // Create a random client ID
    String clientId = "ESP32Client-";
    clientId += String(random(0xffff), HEX);
    // Attempt to connect
    if (client.connect(clientId.c_str())) {
      Serial.println("connected");
      //Once connected, publish an announcement...
      client.publish(MQTT_SERIAL_PUBLISH_CH_1, "00"); //client.publish("/icircuit/presence/ESP32/", "hello world");
      client.publish(MQTT_SERIAL_PUBLISH_CH_2, "00");
      // ... and resubscribe
      client.subscribe(MQTT_SERIAL_RECEIVER_CH_1);
      client.subscribe(MQTT_SERIAL_RECEIVER_CH_2);
    } else {
      Serial.print("failed, rc=");
      Serial.print(client.state());
      Serial.println(" try again in 5 seconds");
      // Wait 5 seconds before retrying
      delay(5000);
    }
  }
}

void callback(char* topic, byte *payload, unsigned int length) {
    Serial.println("-------new message from broker-----");
    Serial.print("channel:");
    Serial.println(topic);
    Serial.print("data:");  
    Serial.write(payload, length);
    Serial.println();
}



void setup(){

  Serial.begin(115200);

  // Initialize the I2C bus (BH1750 library doesn't do this automatically)
  //Wire.begin();
  Wire.begin(18, 19);
  Wire1.begin(21, 22);
  bh1750_a.begin(BH1750::CONTINUOUS_HIGH_RES_MODE, 0x23, &Wire);
  bh1750_b.begin(BH1750::CONTINUOUS_HIGH_RES_MODE, 0x23, &Wire1);
  // On esp8266 you can select SCL and SDA pins using Wire.begin(D4, D3);
  //Conectar a wifi
   setup_wifi();
   client.setServer(mqtt_server, mqtt_port);
   client.setCallback(callback);
   reconnect();
} 

void loop() {
    
  if (!client.connected()) {
    reconnect();
  }
  client.loop();

  //float light_level_a;
  if (bh1750_a.measurementReady()) { 
    lux1 = bh1750_a.readLightLevel();
    char luz1[8];
    dtostrf(lux1,5,2,luz1);
    client.publish(MQTT_SERIAL_PUBLISH_CH_1,luz1);
  }
  float light_level_b; 
  if (bh1750_b.measurementReady()) { 
    lux2 = bh1750_b.readLightLevel();
    char luz2[8];
    dtostrf(lux2,5,2,luz2);
    client.publish(MQTT_SERIAL_PUBLISH_CH_2,luz2); 
  }
  
}

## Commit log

2021-11-02 Create Diagrama de bloques
2021-12-02 Creación Esquematico
    [Esp_32.sch, Pantalla.sch, Telemetria_apicola.kicad_pcb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]
2021-12-14 Foot prints
    [Actuadores.sch, Esp_32.sch, GPS.sch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]
2021-12-14 se trajeron los datos de los compañeros
    [Telemetria_apicola.kicad_pcb]
2022-01-05 sistema de carga de bateria y tension de salida a 5v y 3v3
    [Actuadores.sch, CargadorBateria.sch, Reguladores.sch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]
2022-01-13 cambios termistor
    [CargadorBateria.sch]
2022-01-16 Carga elementos PCB
    [Actuadores.sch, CargadorBateria.sch, Esp_32.sch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]
2022-01-16 footprints terminados
    [CargadorBateria.sch]
2022-01-17 cambios adicionales
    [Telemetria_apicola.kicad_pcb]
2022-01-24 Actualización PCB
    [Telemetria_apicola.kicad_pcb, Telemetria_apicola.sch]
2022-01-25 archivo nuevo de pantalla
2022-01-25 Modificacion PCB
    [Esp_32.sch, Telemetria_apicola.kicad_pcb]
2022-02-01 Archivo pwm añadido a software
2022-02-10 Se sube documento de evidencias Raspberry Pi
2022-02-10 Se sube archivo de protocolo MQTT para probar servidor RPI4
